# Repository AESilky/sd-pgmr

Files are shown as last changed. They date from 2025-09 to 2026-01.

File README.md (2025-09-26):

# Silky Design - Flash ROM Programmer

This is a programmer for the popular SST39SF010A/020A/040 devices from MicroChip.

These devices are 128Mx8, 256Mx8, and 512Mx8, and are used in a number of retro-computing memory and single-board-computers.

The programmer uses a Raspberry Pi Pico2 (RP2350) micro-controller to read image files from a MicroSD card or from the USB port from an application running on a host computer. The RPi Pico2 buffers the image in its internal memory and then writes it to the device.

The programmer can read a Flash device and provides options of saving the device image to the SD card, sending it to a host computer, or writing the image onto another Flash device.

The programmer is powered from the USB port on the RPi Pico2.

The programmer includes a small display and an input knob and switch to navigate through the options, SD card contents, etc.

## Repo Contents

This repo includes:

1. the hardware schematic, PCB layout, and other files needed to produce the PCB.
2. the software for the RPi Pico2, including CMake files to build the RPi Pico2 image.
3. some software for a host computer to communicate with the programmer and transfer files.
4. some component data sheets (for the more unique components)
5. 3D print files for a simple enclosure

## License

Except where noted, the software and hardware for this project is designed/authored by AESilky, and is licensed under the MIT License (included in the repo in the LICENSE file).

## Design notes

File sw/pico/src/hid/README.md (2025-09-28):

# Human Interface Device (HID) and Navigation (NAV) Functionality

## HID

The HID consists of the display panel, rotary encoder (knob), and
cursor switches. The hardware itself is under the control of the
Hardware Runtime, but the overall functionality of the interface
is controlled by this module.

In normal operation, status of the servos and sensors is displayed. There
is also an area that is reserved for outputting debug and informational
messages.

## NAV

The NAV (Navigation) consists of GPS and accelerometer, gyroscope, and
magnetometer sensors that are monitored and value messages posted to the
host.

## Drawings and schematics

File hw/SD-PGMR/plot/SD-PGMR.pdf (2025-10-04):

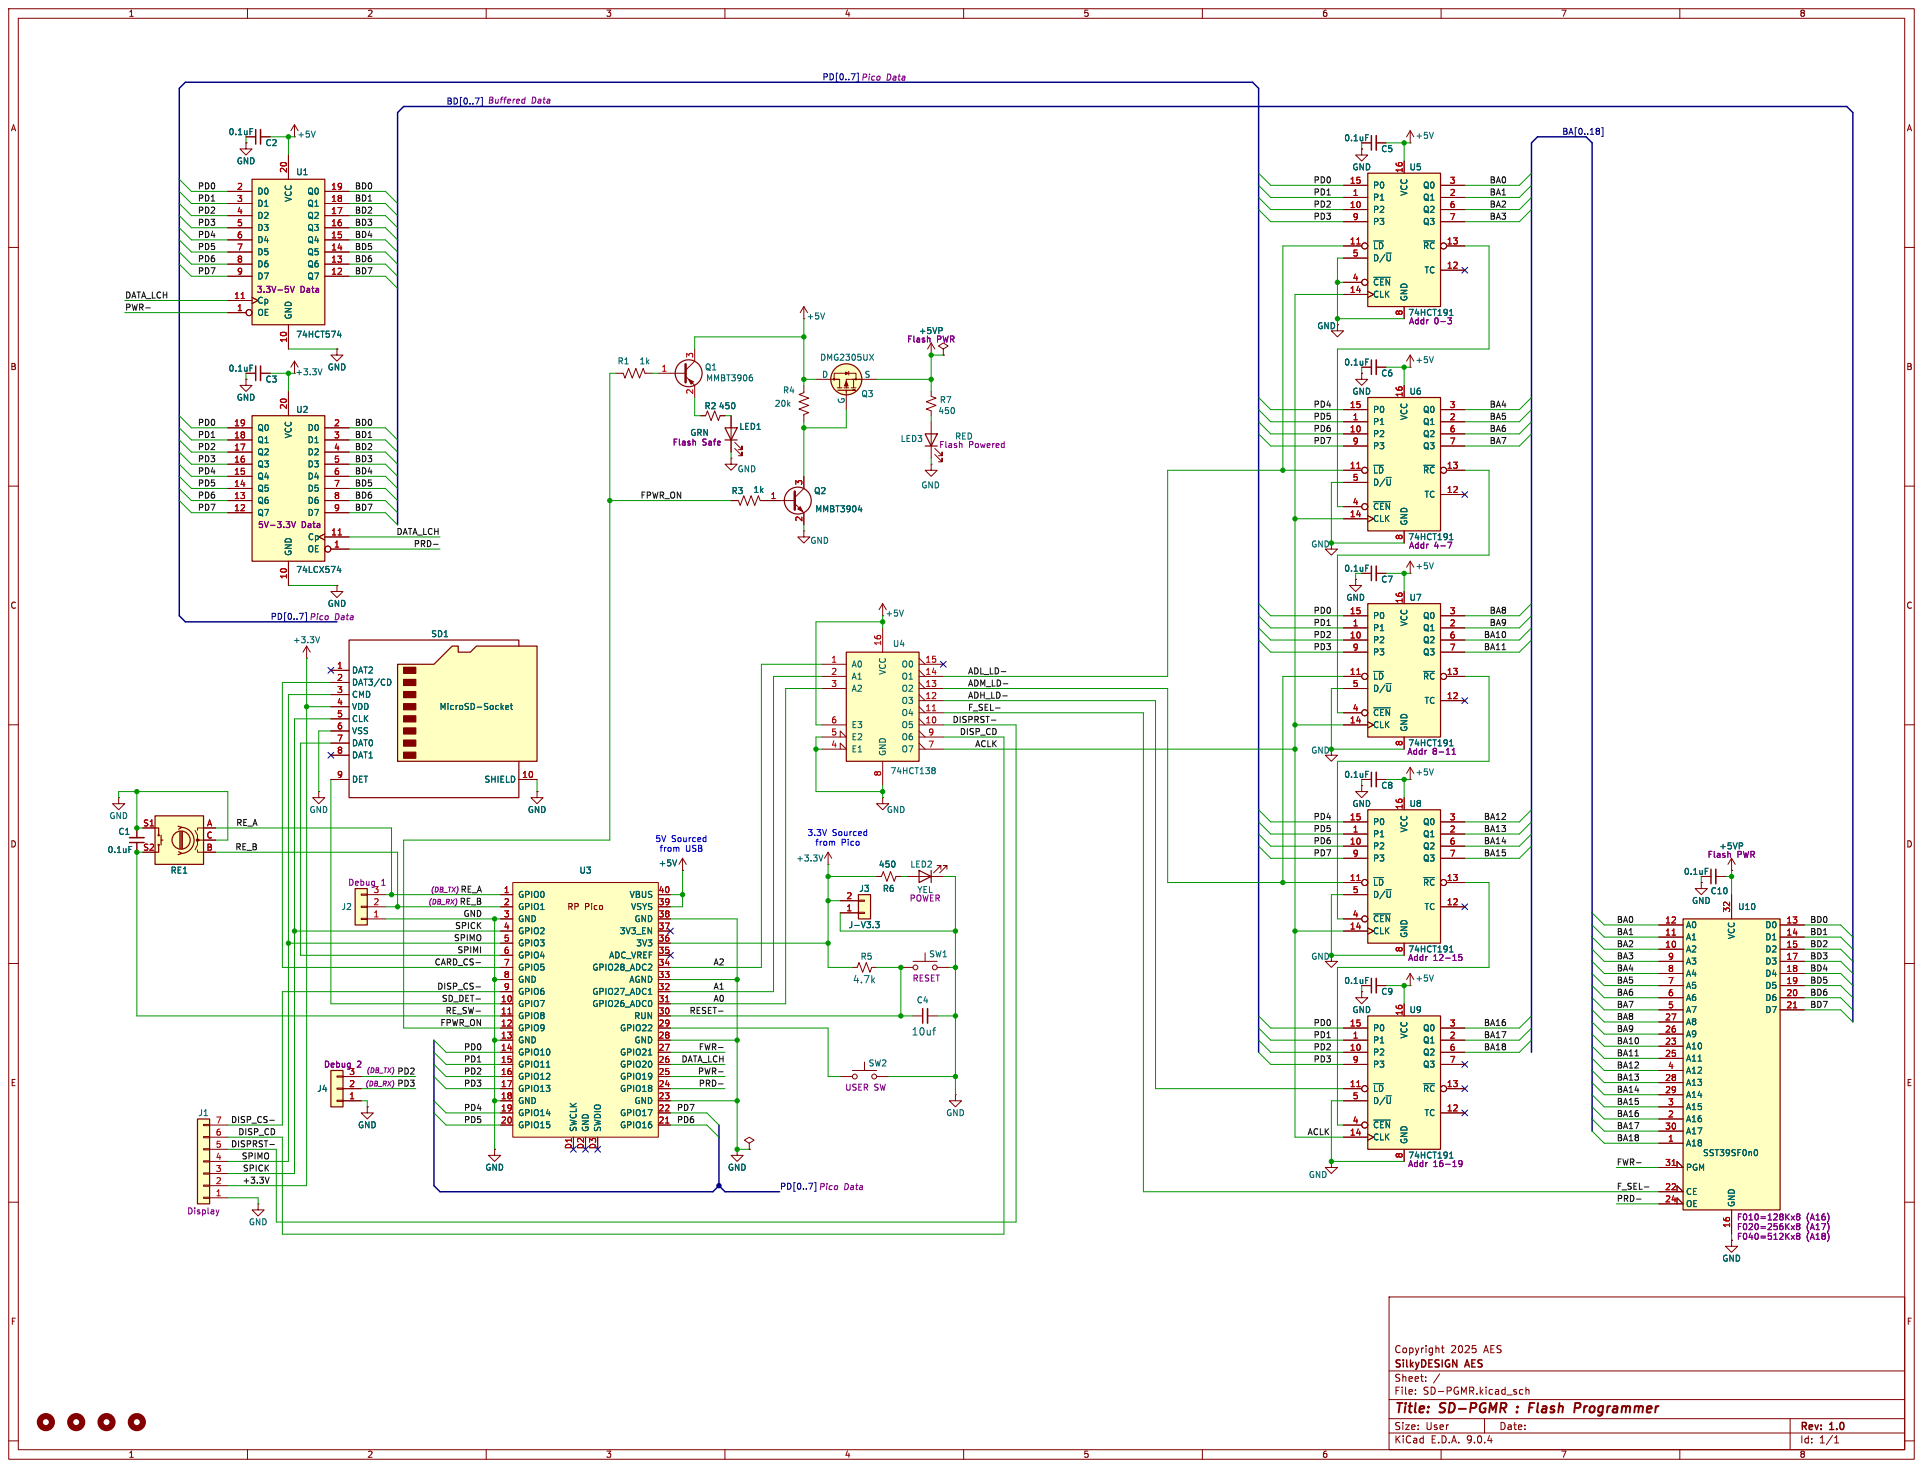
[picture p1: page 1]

3V3 36 ADC_VREF 35 GPIO28_ADC2 34 AGND 33 GPIO27_ADC1 32 GPIO26_ADC0 31 RUN 30 GPIO22 29 GND 28 GPIO21 27 GPIO20 26 GPIO19 25 GPIO18 24 GND 23 GPIO17 22 GPIO16 21 U3

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

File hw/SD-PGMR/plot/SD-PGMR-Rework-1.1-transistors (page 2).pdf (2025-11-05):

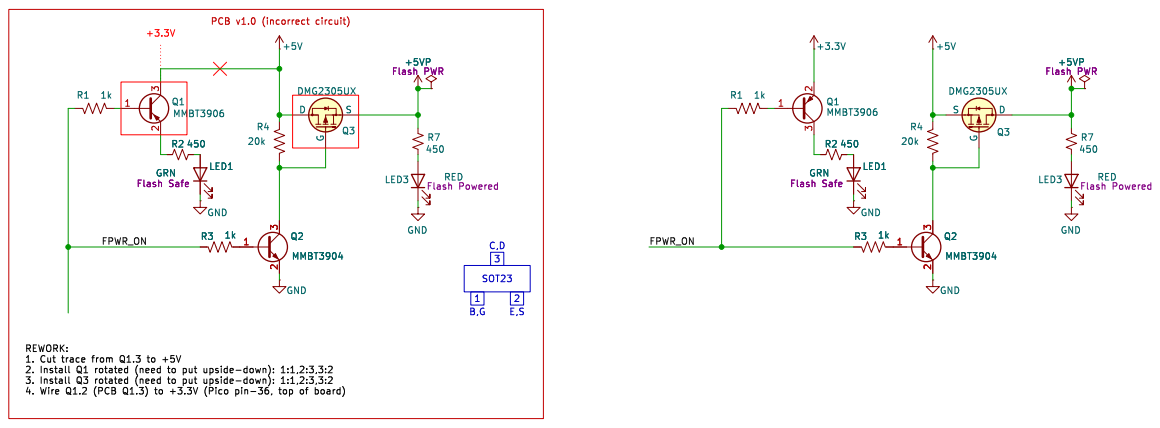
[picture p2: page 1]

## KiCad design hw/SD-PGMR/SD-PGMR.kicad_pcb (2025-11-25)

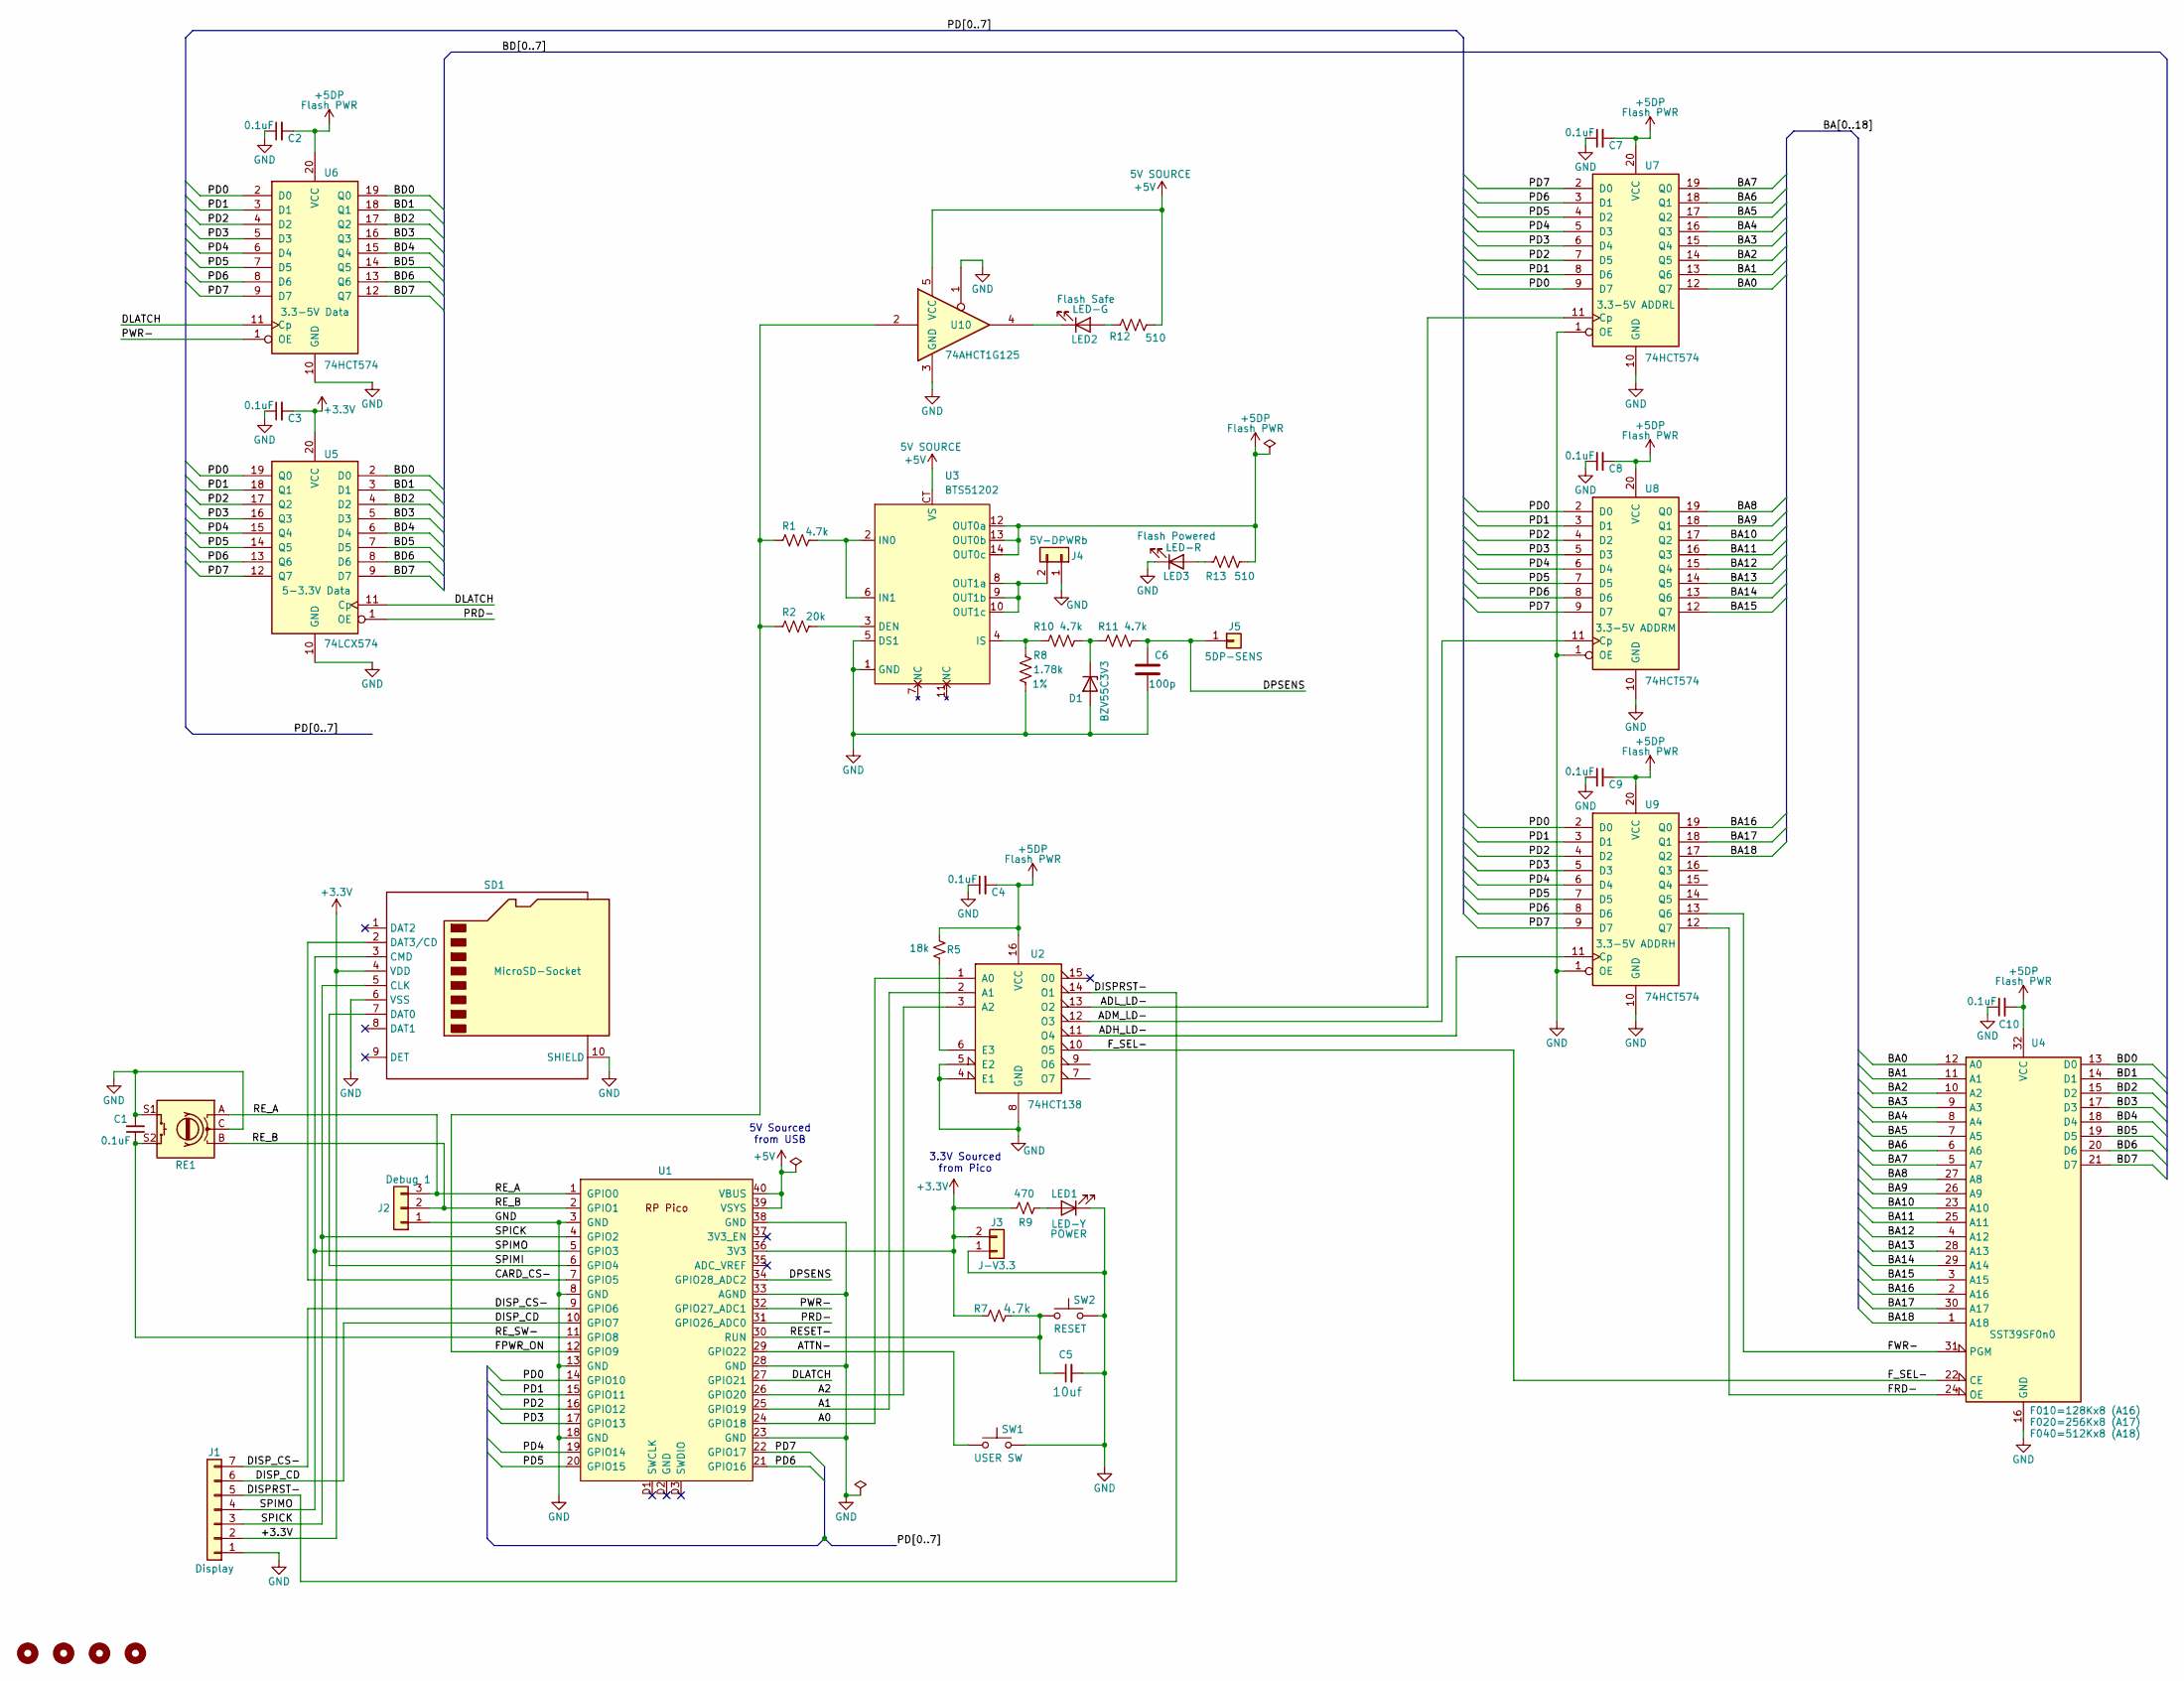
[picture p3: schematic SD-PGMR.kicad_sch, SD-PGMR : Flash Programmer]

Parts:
C1, C2, C3, C4, C7, C8, C9, C10: 0.1uF; C_0603_1608Metric_Pad1.08x0.95mm_HandSolder
C5: 10uf; C_0603_1608Metric_Pad1.08x0.95mm_HandSolder
C6: 100p; C_0603_1608Metric_Pad1.08x0.95mm_HandSolder
D1: BZV55C3V3; D_MiniMELF
H1, H2, H3, H4: MountingHole; MountingHole_2.2mm_M2
J1: CONN_01x07 Socket; PinSocket_1x07_P2.54mm_Vertical
J2: Conn_01x03 HDR; PinHeader_1x03_P2.54mm_Vertical
J3: J-V3.3; PinHeader_1x02_P2.54mm_Vertical
J4: CONN 1x2 HDR; PinHeader_1x02_P2.54mm_Vertical
J5: HDR 1x1 Pin; PinHeader_1x01_P2.54mm_Vertical
LED1: LED-Y; LED_D5.0mm
LED2: LED-G; LED_D5.0mm
LED3: LED-R; LED_D5.0mm
R1, R7, R10, R11: 4.7k; R_0805_2012Metric_Pad1.20x1.40mm_HandSolder
R2: 20k; R_0805_2012Metric_Pad1.20x1.40mm_HandSolder
R5: 18k; R_0805_2012Metric_Pad1.20x1.40mm_HandSolder
R8: 1.78k; R_0805_2012Metric_Pad1.20x1.40mm_HandSolder
R9: 470; R_0805_2012Metric_Pad1.20x1.40mm_HandSolder
R12, R13: 510; R_0805_2012Metric_Pad1.20x1.40mm_HandSolder
RE1: RotEnc-SW; RotaryEncoder_Alps_EC11E-Switch_Vertical_H20mm_MountingHoles
SD1: MicroSD-Socket; AES-SDCard-GCT_MEM2075-00-140-01-A
SW1, SW2: SW PB-MOM; AES-SW_PUSH_SMD_1P1T_NO_45x45mm-CK
U1: AES-Pico; AES-RPi_Pico_SMD_TH
U2: 74HCT138; SOIC-16_3.9x9.9mm_P1.27mm
U3: BTS51202; AES-Inf-BTS5120-DSOP14-BP
U4: SST39SF0n0; DIP_Socket-32_W11.9_W12.7_W15.24_W17.78_W18.5_3M_232-1285-0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
U5: 74LCX574; SOIC-20W_7.5x12.8mm_P1.27mm
U6, U7, U8, U9: 74HCT574; SOIC-20W_7.5x12.8mm_P1.27mm
U10: 74AHCT1G125; SOT-23-5_HandSoldering

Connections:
+3.3V: C3.2, J1.2, J3.2, R7.1, R9.1, SD1.4 (VDD), U1.36 (3V3), U5.20 (VCC)
+5DP: C2.2, C4.2, C7.2, C8.2, C9.2, C10.2, R5.2, R13.2, U2.16 (VCC), U3.12 (OUT0a), U3.13 (OUT0b), U3.14 (OUT0c), U4.32 (VCC), U6.20 (VCC), U7.20 (VCC), U8.20 (VCC), U9.20 (VCC)
+5V: R12.1, U1.39 (VSYS), U1.40 (VBUS), U3.CT (VS), U10.5 (VCC)
/A0: U1.24 (GPIO18), U2.1 (A0)
/A1: U1.25 (GPIO19), U2.2 (A1)
/A2: U1.26 (GPIO20), U2.3 (A2)
/ADH_LD-: U2.11 (O4), U9.11 (Cp)
/ADL_LD-: U2.13 (O2), U7.11 (Cp)
/ADM_LD-: U2.12 (O3), U8.11 (Cp)
/ATTN-: SW1.1, U1.29 (GPIO22)
/BA0: U4.12 (A0), U7.12 (Q7)
/BA1: U4.11 (A1), U7.13 (Q6)
/BA2: U4.10 (A2), U7.14 (Q5)
/BA3: U4.9 (A3), U7.15 (Q4)
/BA4: U4.8 (A4), U7.16 (Q3)
/BA5: U4.7 (A5), U7.17 (Q2)
/BA6: U4.6 (A6), U7.18 (Q1)
/BA7: U4.5 (A7), U7.19 (Q0)
/BA8: U4.27 (A8), U8.19 (Q0)
/BA9: U4.26 (A9), U8.18 (Q1)
/BA10: U4.23 (A10), U8.17 (Q2)
/BA11: U4.25 (A11), U8.16 (Q3)
/BA12: U4.4 (A12), U8.15 (Q4)
/BA13: U4.28 (A13), U8.14 (Q5)
/BA14: U4.29 (A14), U8.13 (Q6)
/BA15: U4.3 (A15), U8.12 (Q7)
/BA16: U4.2 (A16), U9.19 (Q0)
/BA17: U4.30 (A17), U9.18 (Q1)
/BA18: U4.1 (A18), U9.17 (Q2)
/BD0: U4.13 (D0), U5.2 (D0), U6.19 (Q0)
/BD1: U4.14 (D1), U5.3 (D1), U6.18 (Q1)
/BD2: U4.15 (D2), U5.4 (D2), U6.17 (Q2)
/BD3: U4.17 (D3), U5.5 (D3), U6.16 (Q3)
/BD4: U4.18 (D4), U5.6 (D4), U6.15 (Q4)
/BD5: U4.19 (D5), U5.7 (D5), U6.14 (Q5)
/BD6: U4.20 (D6), U5.8 (D6), U6.13 (Q6)
/BD7: U4.21 (D7), U5.9 (D7), U6.12 (Q7)
/CARD_CS-: SD1.2 (DAT3/CD), U1.7 (GPIO5)
/DISPRST-: J1.5, U2.14 (O1)
/DISP_CD: J1.6, U1.10 (GPIO7)
/DISP_CS-: J1.7, U1.9 (GPIO6)
/DLATCH: U1.27 (GPIO21), U5.11 (Cp), U6.11 (Cp)
/DPSENS: C6.2, J5.1, R11.2, U1.34 (GPIO28_ADC2)
/FPWR_ON: R1.1, R2.1, U1.12 (GPIO9), U10.2
/FRD-: U4.24 (OE), U9.12 (Q7)
/FWR-: U4.31 (PGM), U9.13 (Q6)
/F_SEL-: U2.10 (O5), U4.22 (CE)
/PD0: U1.14 (GPIO10), U5.19 (Q0), U6.2 (D0), U7.9 (D7), U8.2 (D0), U9.2 (D0)
/PD1: U1.15 (GPIO11), U5.18 (Q1), U6.3 (D1), U7.8 (D6), U8.3 (D1), U9.3 (D1)
/PD2: U1.16 (GPIO12), U5.17 (Q2), U6.4 (D2), U7.7 (D5), U8.4 (D2), U9.4 (D2)
/PD3: U1.17 (GPIO13), U5.16 (Q3), U6.5 (D3), U7.6 (D4), U8.5 (D3), U9.5 (D3)
/PD4: U1.19 (GPIO14), U5.15 (Q4), U6.6 (D4), U7.5 (D3), U8.6 (D4), U9.6 (D4)
/PD5: U1.20 (GPIO15), U5.14 (Q5), U6.7 (D5), U7.4 (D2), U8.7 (D5), U9.7 (D5)
/PD6: U1.21 (GPIO16), U5.13 (Q6), U6.8 (D6), U7.3 (D1), U8.8 (D6), U9.8 (D6)
/PD7: U1.22 (GPIO17), U5.12 (Q7), U6.9 (D7), U7.2 (D0), U8.9 (D7), U9.9 (D7)
/PRD-: U1.31 (GPIO26_ADC0), U5.1 (OE)
/PWR-: U1.32 (GPIO27_ADC1), U6.1 (OE)
/RESET-: C5.1, R7.2, SW2.1, U1.30 (RUN)
/RE_A: J2.3, RE1.A, U1.1 (GPIO0)
/RE_B: J2.2, RE1.B, U1.2 (GPIO1)
/RE_SW-: C1.1, RE1.S2, U1.11 (GPIO8)
/SPICK: J1.3, SD1.5 (CLK), U1.4 (GPIO2)
/SPIMI: SD1.7 (DAT0), U1.6 (GPIO4)
/SPIMO: J1.4, SD1.3 (CMD), U1.5 (GPIO3)
GND: C1.2, C2.1, C3.1, C4.1, C5.2, C6.1, C7.1, C8.1, C9.1, C10.1, D1.2 (A), J1.1, J2.1, J3.1, J4.1, LED1.1 (K), LED3.1 (K), R8.2, RE1.C, RE1.S1, SD1.6 (VSS), SD1.10 (SHIELD), SW1.2, SW2.2, U1.3 (GND), U1.8 (GND), U1.13 (GND), U1.18 (GND), U1.23 (GND), U1.28 (GND), U1.33 (AGND), U1.38 (GND), U2.4 (E1), U2.5 (E2), U2.8 (GND), U3.1 (GND), U3.5 (DS1), U4.16 (GND), U5.10 (GND), U6.10 (GND), U7.1 (OE), U7.10 (GND), U8.1 (OE), U8.10 (GND), U9.1 (OE), U9.10 (GND), U10.1, U10.3 (GND)
unnamed: D1.1 (K), R10.2, R11.1
unnamed: J4.2, U3.8 (OUT1a), U3.9 (OUT1b), U3.10 (OUT1c)
unnamed: LED1.2 (A), R9.2
unnamed: LED2.2 (A), R12.2
unnamed: LED2.1 (K), U10.4
unnamed: LED3.2 (A), R13.1
unnamed: R5.1, U2.6 (E3)
unnamed: R2.2, U3.3 (DEN)
unnamed: R1.2, U3.2 (IN0), U3.6 (IN1)
unnamed: R8.1, R10.1, U3.4 (IS)

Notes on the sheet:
3.3V Sourced from Pico
5V Sourced from USB

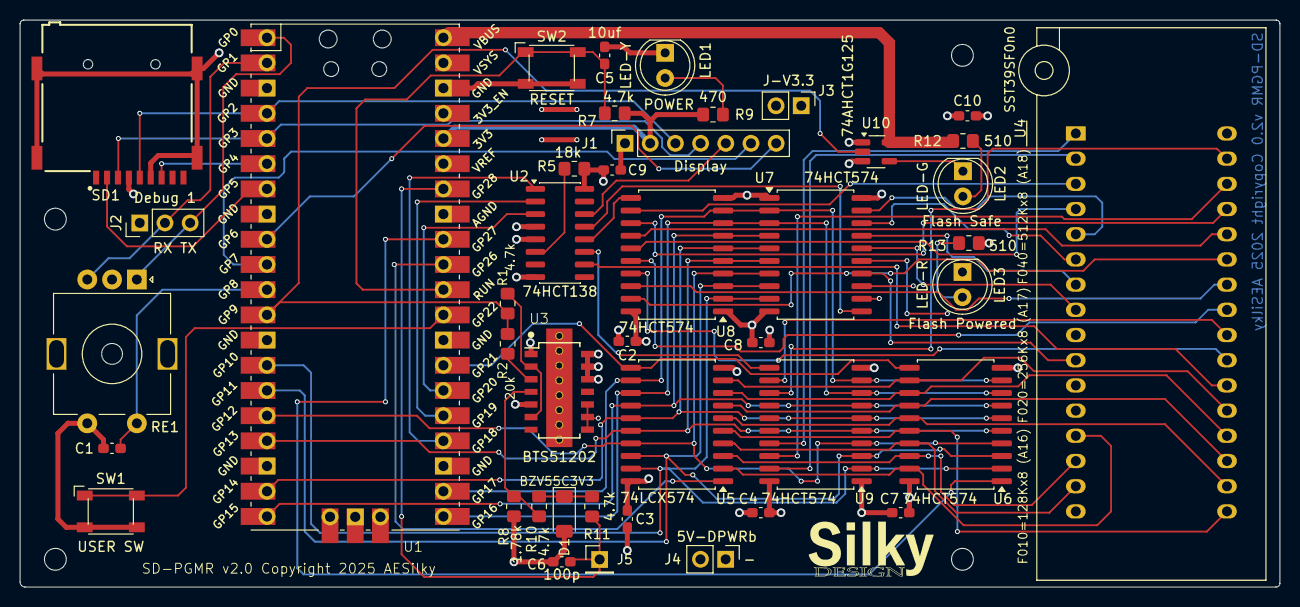
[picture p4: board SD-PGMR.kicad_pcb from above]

Board: 4 copper layers, 127.0 x 57.1 mm, 48 parts (0 on the bottom side), 75 nets.

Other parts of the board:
G1: LOGO; SILKY-DESIGN-logo-0_50-AES

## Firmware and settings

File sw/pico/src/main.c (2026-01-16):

/**
 * SD Flash Programmer main application.
 *
 * Copyright 2023-25 AESilky
 * SPDX-License-Identifier: MIT License
 *
*/
#include "system_defs.h" // Main system/board/application definitions
//
#include "board.h"
#include "debug_support.h"
#include "multicore.h"
#include "picoutil.h"
//
#include "cmt.h"
#include "hwrt/hwrt.h"
//
#include "pico/binary_info.h"

#include <stdio.h>


#define DOT_MS 60 // Dot at 20 WPM
#define UP_MS  DOT_MS
#define DASH_MS (2 * DOT_MS)
#define CHR_SP (3 * DOT_MS)

 // 'H' (....) 'I' (..)
static const int32_t say_hi[] = {
    DOT_MS,
    UP_MS,
    DOT_MS,
    UP_MS,
    DOT_MS,
    UP_MS,
    DOT_MS,
    CHR_SP,
    DOT_MS,
    UP_MS,
    DOT_MS,
    500, // Pause before repeating
    0 };

int main() {
    // useful information for picotool
    bi_decl(bi_program_description("SilkyDESIGN Flash Programmer"));

    // Initialize debug
    debug_init(DIM_BOOT);

    // Board/base level initialization
    if (board_init() != 0) {
        board_panic("Board init failed.");
    }

    led_on_off(say_hi);

    sleep_ms(100);

    // Initialize the multicore subsystem
    multicore_modinit(debug_mode_enabled());

    // Initialize the Cooperative Multi-Tasking subsystem
    cmt_modinit();

    // Launch the Hardware Runtime (core-0 (endless) Message Dispatching Loop).
    // The HWRT starts the appropriate secondary operations (core-1 message loop)
    // (!!! THIS NEVER RETURNS !!!)
    start_hwrt();

    // How did we get here?!
    const char* errmsg = "SDPGMR.main - Somehow we are out of our endless message loop in `main()`!!!";
    debug_trace(errmsg);
    error_printf(errmsg);
    // ZZZ Reboot!!!
    return 0;
}

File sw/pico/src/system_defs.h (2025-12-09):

/*!
 * \brief Definitions for the board hardware.
 * \ingroup board
 *
 * This contains most of the definitions for the board.
 * Some definitions that are truly local to a module are in the module.
 *
 * Copyright 2023-25 AESilky
 *
 * SPDX-License-Identifier: MIT
 */
#ifndef SYSTEM_DEFS_H_
#define SYSTEM_DEFS_H_
#ifdef __cplusplus
extern "C" {
#endif

#include "rppins.h"

#include "pico/stdlib.h"
#undef putc     // Undefine so the standard macros will not be used
#undef putchar  // Undefine so the standard macros will not be used

#include "hardware/adc.h"
#include "hardware/gpio.h"
#include "hardware/pio.h"
#include "hardware/spi.h"
#include "hardware/uart.h"
#include "pico/multicore.h"

#define ADC_INPUT_0             0               // ADC-0 on GPIO-26 (used with 'adc_select_input')
#define ADC_INPUT_1             1               // ADC-1 on GPIO-27 (used with 'adc_select_input')
#define ADC_INPUT_2             2               // ADC-2 on GPIO-28 (used with 'adc_select_input')
#define ADC_CHIP_TEMP           3               // Internal temperature sensor  (used with 'adc_select_input')

// SPI
//
// Note: Values (Pins) are the GPIO number, not the physical pins on the device.
//

// SPI 0 is used for the SD Card and Display.
//
#define SPI_SD_DISP_DEVICE      spi0            // Hardware SPI to use
#define SPI_SD_DISP_MISO        GP4
#define SPI_SD_DISP_MOSI        GP3
#define SPI_SD_DISP_SCK         GP2
#define SPI_SD_CS               GP5
#define SPI_DISPLAY_CS          GP6
#define SPI_DISPLAY_CTRL        GP7
#define SPI_SLOW_SPEED         (50 * 1000)      // Very slow speed for init ops
#define SPI_SD_DISP_SPEED      (800 * 1000)     // SPI at 800KHz
#define SPI_CS_ENABLE           0               // Chip Select is active LOW
#define SPI_CS_DISABLE          1               // Chip Select is active LOW

// Certain operations are controlled by a 3:8 decoder (74138)
// The decoder is driven by GPIOs 28(A0), 27(A1), 26(A0)
// The values below are the values used to generate each function.
//
#define OP8_BIT0                GP18            // A0
#define OP8_BIT1                GP19            // A1
#define OP8_BIT2                GP20            // A2
#define OP8_BITS_MASK           0x001C0000      // Mask to set all 3 bits at once: 0000 0000 0001 1100 0000 0000 0000 0000
#define OP8_BITS_SHIFT          18              // Right-Shift needed to move the OP8 bits to the correct GPIO position
// OP8 Operations
#define OP8_NONE                 0              // 0 = No-Op
#define OP8_NOP                  1              // Display Reset
#define OP8_ADDRL_LD             2              // Addr Latch LOW Load
#define OP8_ADDRM_LD             3              // Addr Latch MID Load
#define OP8_ADDRH_LD             4              // Addr Latch HIGH Load
#define OP8_DEV_SEL              5              // Device (FlashROM) Select
#define OP8_NOP2                 6              // No-Operation
#define OP8_NOP3                 7              // No-Operation

// Operations controlled directly by a GPIO
//
#define DISPLAY_RST             GP28            // Hard-reset the display
#define OP_DEVICE_PWR           GP9             // Turns the device power on
#define OP_DATA_RD              GP26            // Enable data from the device to the bus
#define OP_DATA_WR              GP27            // Enable data from the bus to the device
#define OP_DATA_LATCH           GP21            // Latch data to/from the bus/device

// Data Bus
//
#define DATA0                   GP10
#define DATA1                   GP11
#define DATA2                   GP12
#define DATA3                   GP13
#define DATA4                   GP14
#define DATA5                   GP15
#define DATA6                   GP16
#define DATA7                   GP17
#define DATA_BUS_MASK           0x0003FC00      // Mask to set all 8 bits at once: 0000 0000 0000 0011 1111 1100 0000 0000
#define DATA_BUS_SHIFT          10              // Shift to move an 8-bit value up/down to/from the DATA Bus

// PIO Blocks
//
#define PIO_ROTARY_BLOCK        pio1            // PIO Block 1 is used to decode the quadrature signal
#define PIO_ROTARY_SM            0              // State Machine 0 is used for the rotary quad decode
#define PIO_ROTARY_IRQ          PIO1_IRQ_0      // PIO IRQ to use for Rotary reading change
#define PIO_ROTARY_IRQ_IDX       0              // PIO IRQ index for the Rotary reading change

// Rotary Encoder Input
// This is a A/B quadrature encoder that can be decoded using a PIO (must be sequential)
#define ROTARY_A_GPIO           GP0
#define ROTARY_B_GPIO           GP1
#define ROTARY_SW_GPIO          GP8
// Command/Attention switch (separate from rotary encoder)
#define CMD_ATTN_SW_GPIO        GP22
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

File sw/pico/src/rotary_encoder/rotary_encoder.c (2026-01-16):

/**
 * Some content Copyright (c) 2021 pmarques-dev @ github
 *
 * Modifications Copyright 2023-25 aesilky
 *
 * SPDX-License-Identifier: BSD-3-Clause
 */
//
// ---- quadrature encoder interface example (from pico-examples)
//
// the PIO program reads phase A/B of a quadrature encoder and increments or
// decrements an internal counter to keep the current absolute step count
// updated. At any point, the main code can query the current count by using
// the quadrature_encoder_*_count functions. The counter is kept in a full
// 32 bit register that just wraps around. Two's complement arithmetic means
// that it can be interpreted as a 32-bit signed or unsigned value, and it will
// work anyway.
//
// As an example, a two wheel robot being controlled at 100Hz, can use two
// state machines to read the two encoders and in the main control loop it can
// simply ask for the current encoder counts to get the absolute step count. It
// can also subtract the values from the last sample to check how many steps
// each wheel as done since the last sample period.
//
// One advantage of this approach is that it requires zero CPU time to keep the
// encoder count updated and because of that it supports very high step rates.
//

// Modifications and additions...
//
// Use interrupts to know when the encoder has moved.
// Add reading of the switch, also using the interrupt to know when it has changed.
//
#include "system_defs.h"
#include "rotary_encoder.h"

#include "board.h"
#include "picoutil.h"
#include "cmt.h"

#include "pico/stdlib.h"
#include "hardware/clocks.h"
#include "hardware/pio.h"
#include "hardware/timer.h"
#include "hardware/gpio.h"

#include "quadrature_encoder.pio.h"

#include <stdio.h>


#define _PIN_rotary_ENC_AB ROTARY_A_GPIO    // Base pin to connect the A phase of the encoder.

static volatile bool _initialized;
                                            // The B phase must be connected to the next pin
static volatile int16_t _enc_delta;
static volatile int32_t _enc_t_last;
static volatile int32_t _enc_t_delta;
static volatile int32_t _enc_value;
static volatile int32_t _enc_velocity;

static void _gpio_event_string(char *buf, uint32_t events);


// max_step_rate is used to lower the clock of the state machine to save power
// if the application doesn't require a very high sampling rate. Passing zero
// will set the clock to the maximum, which gives a max step rate of around
// 8.9 Msteps/sec at 125MHz
static inline void _quadrature_encoder_program_init(PIO pio, uint sm, uint offset, uint pin, int max_step_rate) {
    pio_sm_set_consecutive_pindirs(pio, sm, pin, 2, false);
    pio_sm_config c = quadrature_encoder_program_get_default_config(offset);
    sm_config_set_in_pins(&c, pin); // for WAIT, IN
    sm_config_set_jmp_pin(&c, pin); // for JMP
    // shift to left, autopull disabled
    sm_config_set_in_shift(&c, false, false, 32);
    // don't join FIFO's
    sm_config_set_fifo_join(&c, PIO_FIFO_JOIN_NONE);
    // passing "0" as the sample frequency,
    if (max_step_rate == 0) {
        sm_config_set_clkdiv(&c, 1.0);
    }
    else {
     // one state machine loop takes at most 14 cycles
        float div = (float)clock_get_hz(clk_sys) / (14 * max_step_rate);
        sm_config_set_clkdiv(&c, div);
    }
    pio_sm_init(pio, sm, offset, &c);
    pio_sm_set_enabled(pio, sm, true);
}
// When requesting the current count we may have to wait a few cycles (average
// ~11 sysclk cycles) for the state machine to reply. If we are reading multiple
// encoders, we may request them all in one go and then fetch them all, thus
// avoiding doing the wait multiple times. If we are reading just one encoder,
// we can use the "get_count" function to request and wait
static inline void _quadrature_encoder_request_count(PIO pio, uint sm) {
    pio->txf[sm] = 1;
}
static inline int32_t _quadrature_encoder_fetch_count(PIO pio, uint sm) {
    bool mt = true;
    for (int i = 0; mt && i < 1000; i++) {
        mt = pio_sm_is_rx_fifo_empty(pio, sm);
    }
    return (mt ? -1 : pio->rxf[sm]);
}
static inline int32_t _quadrature_encoder_get_count(PIO pio, uint sm) {
    _quadrature_encoder_request_count(pio, sm);
    return _quadrature_encoder_fetch_count(pio, sm);
}


int32_t re_count() {
    return _enc_value;
}

int16_t re_delta() {
    return _enc_delta;
}

int32_t re_tdelta() {
    return _enc_t_delta;
}

int32_t re_tlast() {
    return _enc_t_last;
}

int32_t re_velocity() {
    return _enc_velocity;
}

void re_turn_handler(uint phase) {
    if (phase % 2 == 0) {
        // Request count on EVEN
        _quadrature_encoder_request_count(PIO_ROTARY_BLOCK, PIO_ROTARY_SM);
        return;
    }
    // Get the count on ODD
    int32_t new_value;
    // note: thanks to two's complement arithmetic delta will always
    // be correct even when new_value wraps around MAXINT / MININT
    new_value = _quadrature_encoder_fetch_count(PIO_ROTARY_BLOCK, PIO_ROTARY_SM);
    // We use '-1' as a special flag to indicate that there wasn't any data available.
    if (new_value != -1) {
        _enc_delta = new_value - _enc_value;
        _enc_value = new_value;
        uint32_t now = now_ms();
        _enc_t_delta = now - _enc_t_last;
        _enc_t_last = now;
        if (_enc_delta != 0) {
            if (_enc_t_delta != 0) {
                _enc_velocity = (_enc_delta * 1000) / _enc_t_delta;
            }
            cmt_msg_t msg;
            cmt_msg_init(&msg, MSG_ROTARY_CHG);
            msg.data.value16 = _enc_delta;
            postAPPMsgDiscardable(&msg);
        }
    }
}



void re_modinit() {
    if (_initialized) {
        board_panic("!!! re_module_init: Called more than once !!!");
    }
    _enc_delta = 0;
    _enc_value = 0;
    _enc_t_delta = now_ms();
    _enc_t_last = _enc_t_delta;
    // GPIO initialize if DEBUG_TRACE isn't enabled.
#ifndef DEBUG_TRACE_ENABLE
    gpio_set_function(ROTARY_A_GPIO, GPIO_FUNC_SIO);
    gpio_set_dir(ROTARY_A_GPIO, GPIO_IN);
    gpio_set_pulls(ROTARY_A_GPIO, true, false);
    gpio_set_function(ROTARY_B_GPIO, GPIO_FUNC_SIO);
    gpio_set_dir(ROTARY_B_GPIO, GPIO_IN);
    gpio_set_pulls(ROTARY_B_GPIO, true, false);
    uint offset = pio_add_program(PIO_ROTARY_BLOCK, &quadrature_encoder_program);
    _quadrature_encoder_program_init(PIO_ROTARY_BLOCK, PIO_ROTARY_SM, offset, _PIN_rotary_ENC_AB, 20000);
#endif

    _initialized = true;
}

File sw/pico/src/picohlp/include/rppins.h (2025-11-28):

/*!
 * \brief RP2040 & RP2050 GPIO Pins.
 * @ingroup board
 *
 * The GPIO names to numbers for Pico, Pico2, and Adafruit KB2040.
 * The .
 *
 * Copyright 2023-25 AESilky
 *
 * SPDX-License-Identifier: MIT
 */
#ifndef RPPINS_H_
#define RPPINS_H_
#ifdef __cplusplus
extern "C" {
#endif

#define STRINGIFY_HELPER(x) #x
#define STRINGIFY(x) STRINGIFY_HELPER(x)

#if ADAFRUIT_KB2040
// ADAFRUIT_KB2040 PINS
//
// StemmaQT: 1=GND 2=3.3V 3=GP12(SDA0) 4=GP13(SCL0)
#define GP0     0       // Pin 2
#define GP1     1       // Pin 3
#define GP2     2       // Pin 6
#define GP3     3       // Pin 7
#define GP4     4       // Pin 8
#define GP5     5       // Pin 9
#define GP6     6       // Pin 10
#define GP7     7       // Pin 11
#define GP8     8       // Pin 12
#define GP9     9       // Pin 13
#define GP10    10      // Pin 14
#define GP11    11      // Button
#define GP12    12      // StemmaQT 3
#define GP13    13      // StemmaQT 4
//#define GP14    14      // NA
//#define GP15    15      // NA
//#define GP16    16      // NA
#define GP17    17      // NEOPIXEL
#define GP18    18      // Pin 17
#define GP19    19      // Pin 15
#define GP20    20      // Pin 16
//#define GP21    21      // NA
//#define GP22    22      // NA
#define GP26    26      // Pin 18
#define GP27    27      // Pin 19
#define GP28    28      // Pin 20
#define GP29    29      // Pin 21
#define RPADC0  GP26
#define RPADC1  GP27
#define RPADC2  GP28
#define RPADC3  GP29
#else
#define GP0     0       // Pin 1
#define GP1     1       // Pin 2
#define GP2     2       // Pin 4
#define GP3     3       // Pin 5
#define GP4     4       // Pin 6
#define GP5     5       // Pin 7
#define GP6     6       // Pin 9
#define GP7     7       // Pin 10
#define GP8     8       // Pin 11
#define GP9     9       // Pin 12
#define GP10    10      // Pin 14
#define GP11    11      // Pin 15
#define GP12    12      // Pin 16
#define GP13    13      // Pin 17
#define GP14    14      // Pin 19
#define GP15    15      // Pin 20
#define GP16    16      // Pin 21
#define GP17    17      // Pin 22
#define GP18    18      // Pin 24
#define GP19    19      // Pin 25
#define GP20    20      // Pin 26
#define GP21    21      // Pin 27
#define GP22    22      // Pin 29
#define GP23    23      // Controls Power Mode: 0=PFM 1=PWM
#define GP24    24      // Reads VBUS: 0=VBUS Absent 1=VBUS Present
#define GP25    25      // LED
#define GP26    26      // Pin 31
#define GP27    27      // Pin 32
#define GP28    28      // Pin 34
#define RPADC0  GP26
#define RPADC1  GP27
#define RPADC2  GP28
#define RPADC3  29      // ADC3 is used to detect 3.3V enabled
#endif

#ifdef __cplusplus
}
#endif
#endif // RPPINS_H_

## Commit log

2025-09-23 Update gitignore to skip KiCad lock and backup files.
2025-09-26 PCB v1.0 (ordered)
    [SD-PGMR-B_Cu.gbr, SD-PGMR-B_Mask.gbr, SD-PGMR-B_Paste.gbr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]
2025-10-04 PCB: BOM and Assy file created
    [SD-PGMR.kicad_pcb]
2025-10-05 Device (Flash) operations.
2025-10-06 Debugging Support: stdio starts on uart, switch to usb.
2025-10-24 Shell: added. Device: Corrected signal generation.
    [pdops.c]
2025-10-31 Shell: Change ESC sequence buffer size.
2025-10-31 Shell: Add an error printf.
2025-11-05 PGMR: Last of this PCB. New version needed for device power.
    [SD-PGMR.kicad_sch, eco-0001_a.kicad_sch]
2025-11-25 Re-design and re-layout with new power circuit
    [SD-PGMR-B_Cu.gbr, SD-PGMR-B_Mask.gbr, SD-PGMR-B_Paste.gbr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]
2025-11-30 Rotary: Fix retrieve value problem. PD: add Power-Mode.
    [board.c, cmds.c, dispspi_ops.c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]
2025-12-01 MenuMgr: First cut functioning. Still needs work.
2025-12-10 Program device from binary image file.

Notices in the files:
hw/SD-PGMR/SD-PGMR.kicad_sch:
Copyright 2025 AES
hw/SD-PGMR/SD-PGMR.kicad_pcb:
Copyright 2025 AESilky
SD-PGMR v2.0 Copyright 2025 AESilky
